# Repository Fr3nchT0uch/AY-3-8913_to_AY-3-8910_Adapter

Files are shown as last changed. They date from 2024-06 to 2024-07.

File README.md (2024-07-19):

# AY-3-8913 to AY-3-8910 Adapter

A simple adapter to replace the AY-3-8913 with the AY-3-8910 (or the YM2149)

## Why to replace the AY-3-8913 ?
If you've read this article https://www.fenarinarsa.com/?p=3183, you know that there's a chance your Mockingboard with AY-3-8913 will sound *weird* under certain circumstances.

Here a short video to hear the difference between a faulty AY-3-8913 and an AY-3-8910 in action (featuring Digidream 2): https://www.youtube.com/watch?v=_qslugOY2Dw

That's why we decided to do an adapter to easily replace the AY-3-8913 with the AY-3-8910 (or the YM2149) which does not suffer from the same issue and is more readily available.
We have made several designs giving you the choice for your use!
And they can of course be used as a basis for your own project! 

**Note about the Phasor Card**: these adapters are designed to be used primarily on a *Mockingboard*. For the *Phasor*, as there are 4 AY-3-8913s potentially to be replaced, it will probably be necessary to use a *daughter board* as adapter. This is beyond the scope of this project (for now...)

## Credits:  
Original idea: French Touch (grouik/fenarinarsa)  
http://fr3nch.t0uch.free.fr/  
Final design (and all the hard work!): Mr Jean-Fred  
https://github.com/Jean-Fred64

*French Touch would especially like to thank Mr Jean-Fred, without whom this project would never have been possible. It's thanks to him that an embryonic schematic was transformed into a viable project!*

## License:
GNU GENERAL PUBLIC LICENSE 3

## Reference:
Datasheets:  
AY-3-8910: https://map.grauw.nl/resources/sound/generalinstrument_ay-3-8910.pdf  
YM2149: http://www.ym2149.com/ym2149.pdf  

Mockingboard Info:  
https://en.wikipedia.org/wiki/Mockingboard
https://www.reactivemicro.com/product/mockingboard-assembled-or-kit/

Manufacturing PCB:  
https://www.kicad.org/  
https://jlcpcb.com/  
https://www.pcbway.com/

----  
## PCB designs:

## "Angle" version for Mockingboard (Two different PCBs for each AY-3-8913)
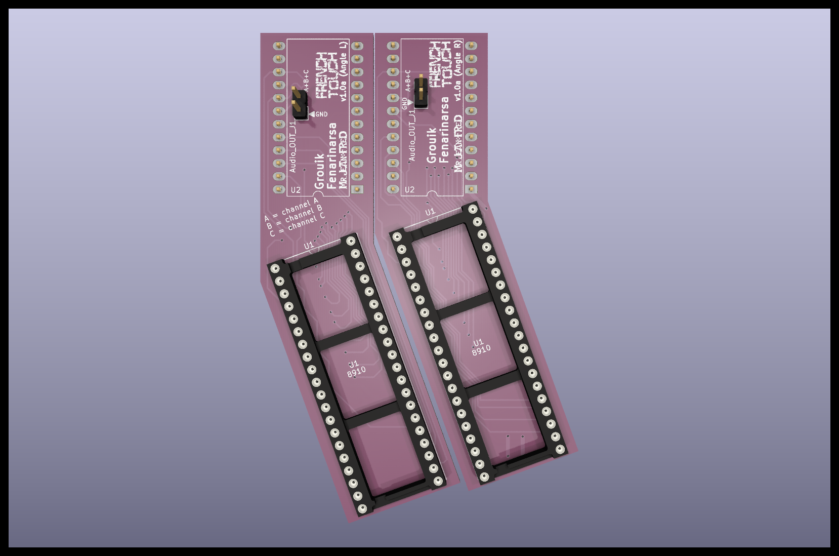
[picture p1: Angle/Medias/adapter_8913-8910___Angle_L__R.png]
adapter 8913-8910 Angle Left

 
**LEFT** for *top* AY-3-8913:
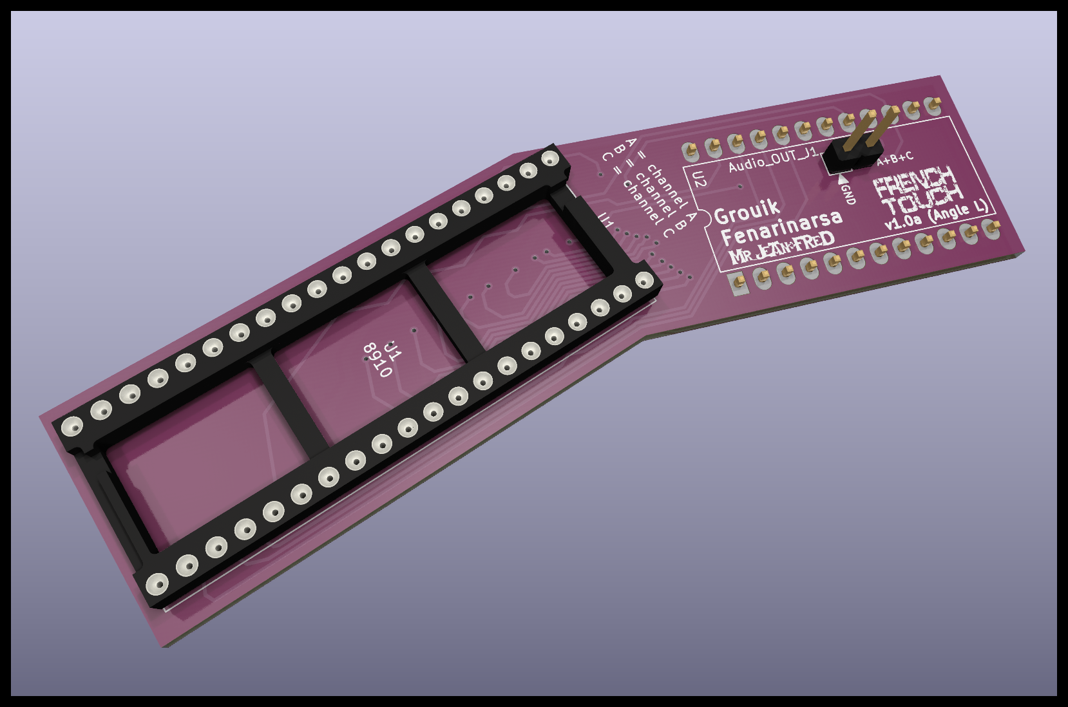
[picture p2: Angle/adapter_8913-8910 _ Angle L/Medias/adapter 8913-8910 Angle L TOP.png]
adapter 8913-8910 Angle Left


**RIGHT** for *bottom* AY-3-8913:
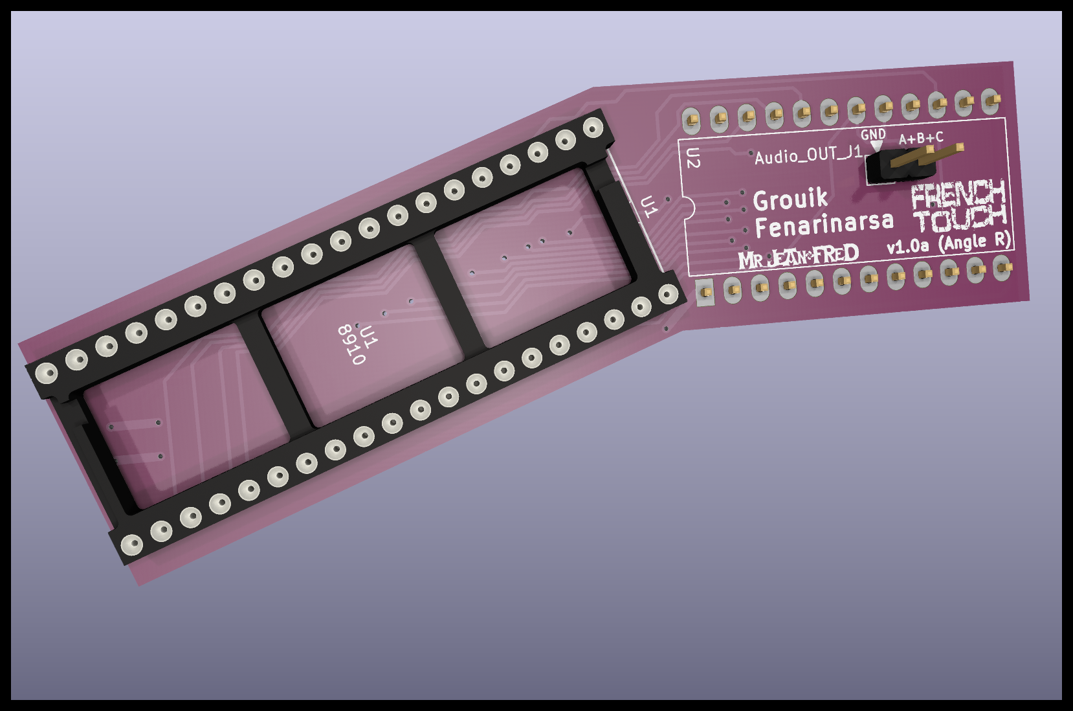
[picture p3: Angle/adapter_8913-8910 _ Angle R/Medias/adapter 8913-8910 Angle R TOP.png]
adapter 8913-8910 Angle Left


- to replace one or **two** AY-3-8913 on your Mockingboard.
- you must use each version for the TOP and BOTTOM AY-3-8913 on your Mockbingboard.
- note: pay attention to the insertion direction of the AY-3-8910 on the adapter.

----  

## "Triangle" version for Mockingboard (A single PCB for the two AY-3-8913s)
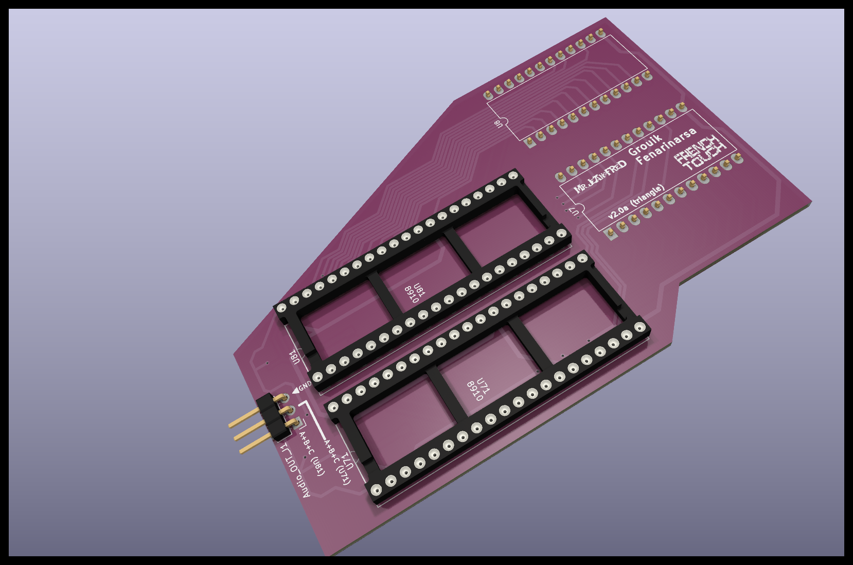
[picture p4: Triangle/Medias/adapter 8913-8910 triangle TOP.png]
adapter 8913-8910 zoom header


- alternative (and ultimate) version to replace the TWO AY-3-8913 on the Mockingboard on the same board.

----
## "Normal" general version
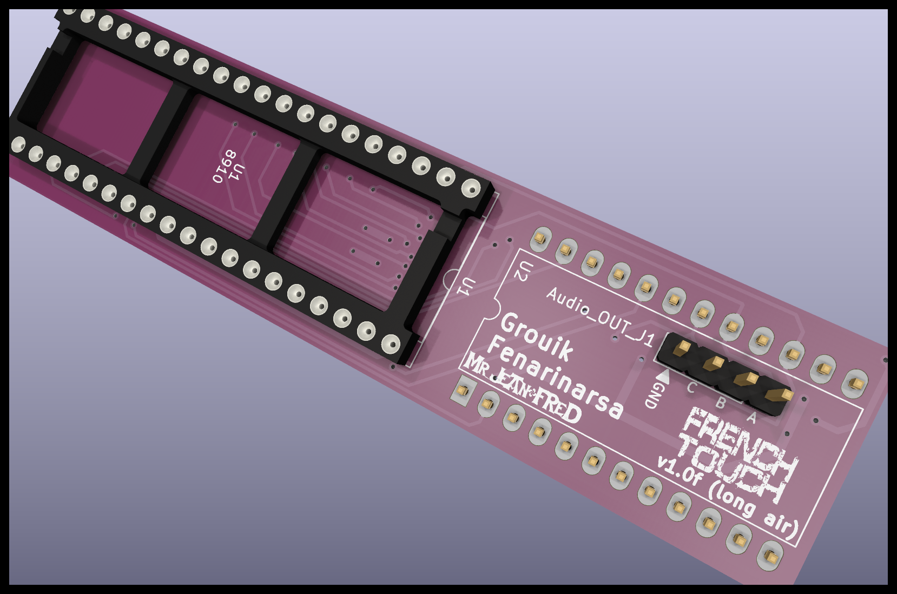
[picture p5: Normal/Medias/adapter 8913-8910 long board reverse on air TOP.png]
adapter 8913-8910 Normal


- to replace only **one** AY-3-8913 on the Mockingboard (the **bottom** one only!).
- to replace the AY-3-8913 on other machines (for example: some old Pinball *soundcards*).
- note: pay attention to the insertion direction of the AY-3-8910 on the adapter.

- **WARNING**: do not use this model if you want to replace the **TWO** AY-3-8913s on your Mockingboard because you will not be able to close the Apple II cover! Use the other designs instead!

## Audio Output:

Each PCD design has an **Audio Output** (pins) for direct connection to the AY-3-8910/YM2149 without using the Mockingboard amplification part. This allows for much better quality with a line level output.

To be heard here: https://www.youtube.com/watch?v=SWxKD_74ifs

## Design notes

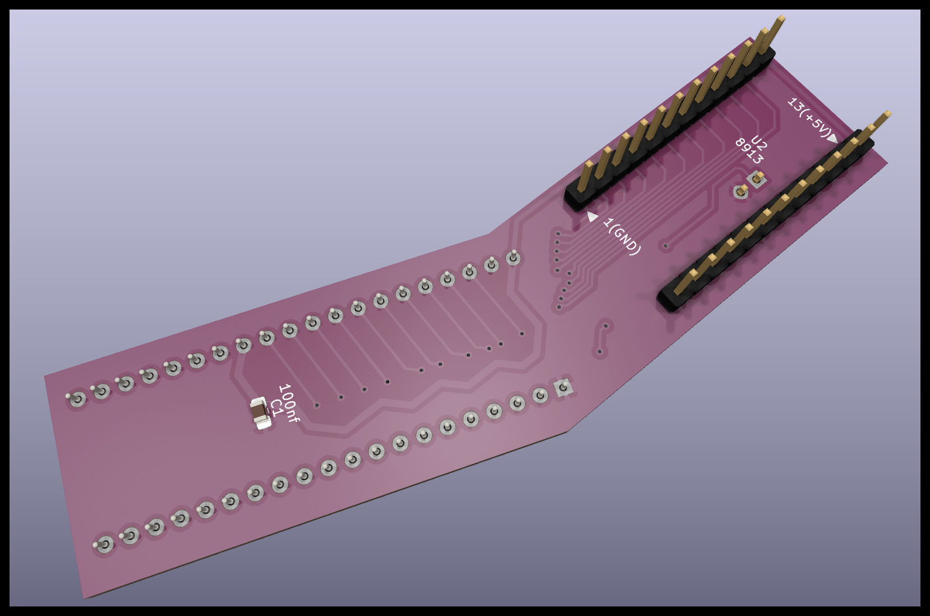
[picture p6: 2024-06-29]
Angle/adapter_8913-8910 _ Angle L/Medias/adapter 8913-8910 Angle L BACK.png

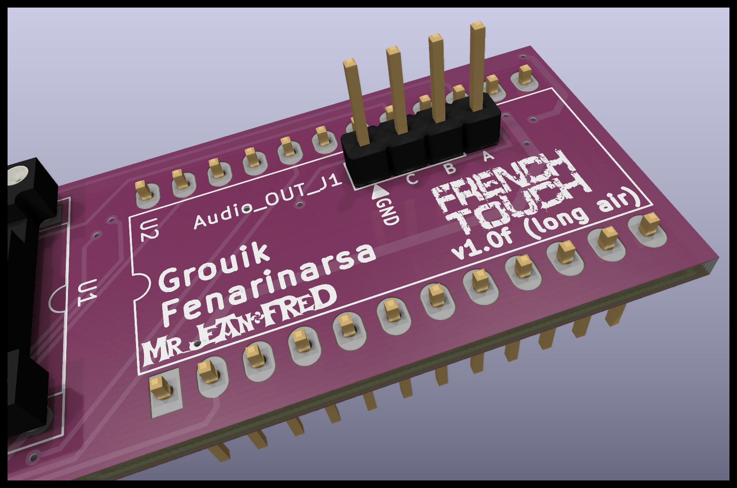
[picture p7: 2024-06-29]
Normal/Medias/adapter 8913-8910 zoom header pin 2.54 mm.png

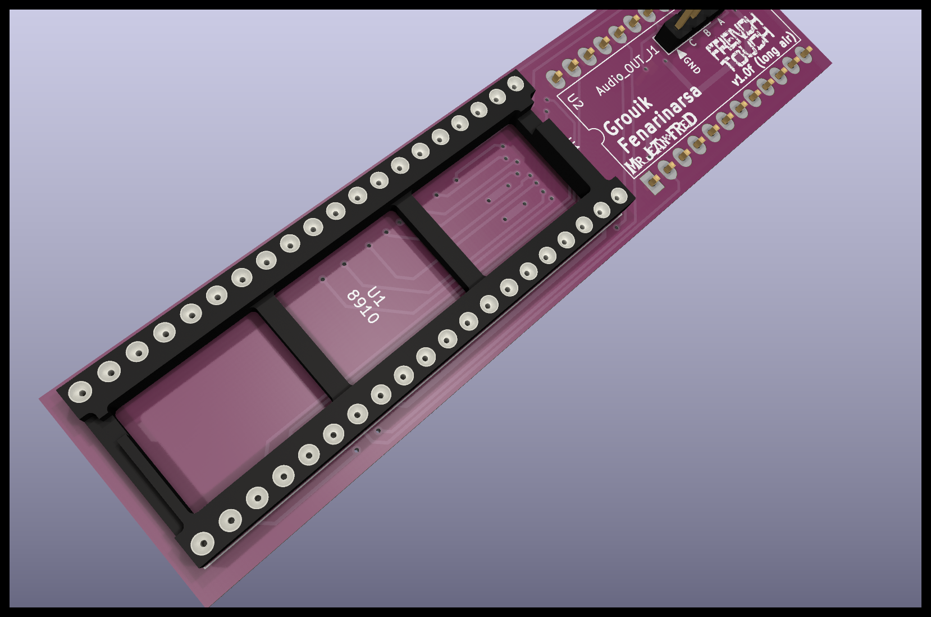
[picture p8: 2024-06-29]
Normal/Medias/adapter 8913-8910 8910.png

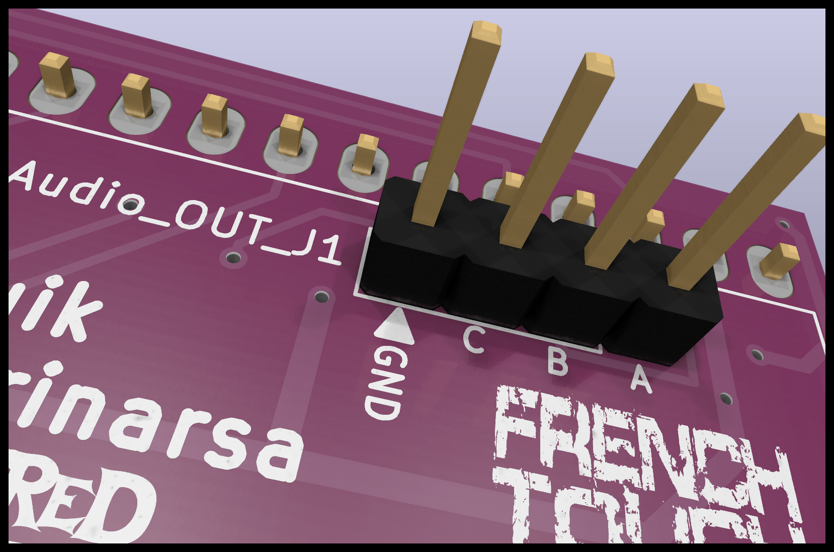
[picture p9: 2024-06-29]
Normal/Medias/adapter 8913-8910 zoom header pin.png

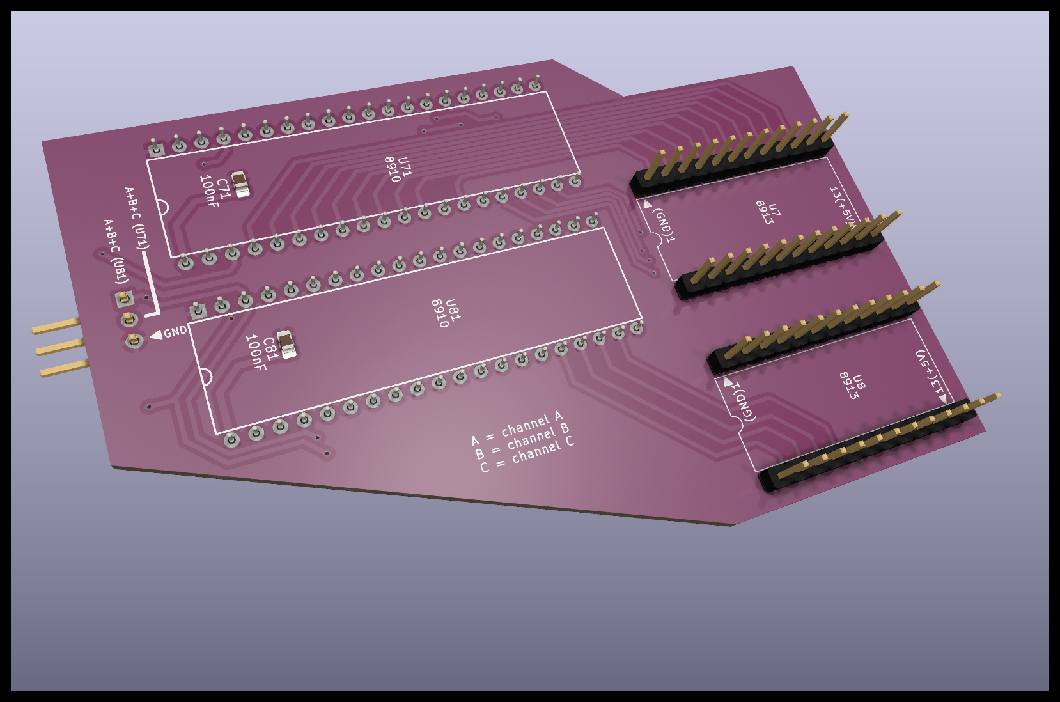
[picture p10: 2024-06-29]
Triangle/Medias/adapter 8913-8910 triangle BACK.png

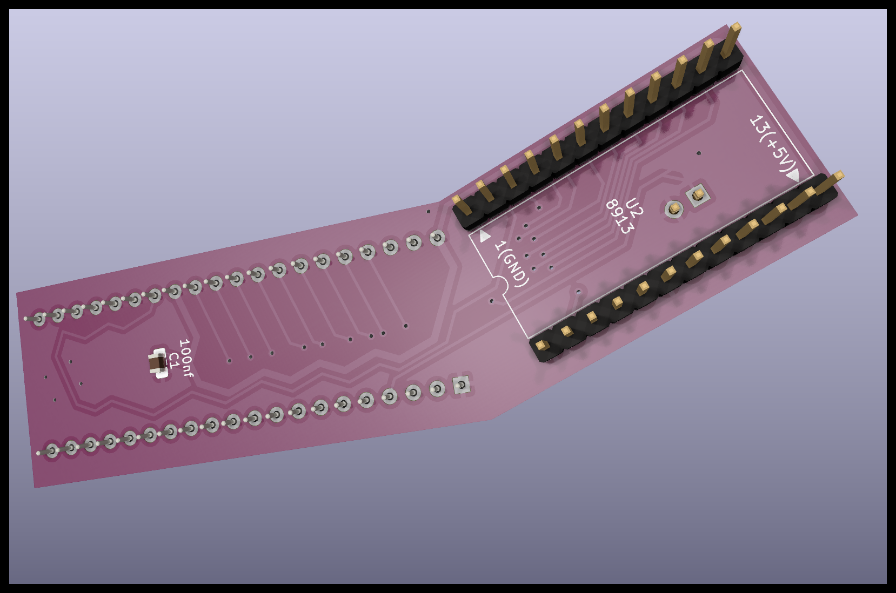
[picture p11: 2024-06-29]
Angle/adapter_8913-8910 _ Angle R/Medias/adapter 8913-8910 Angle R BACK.png

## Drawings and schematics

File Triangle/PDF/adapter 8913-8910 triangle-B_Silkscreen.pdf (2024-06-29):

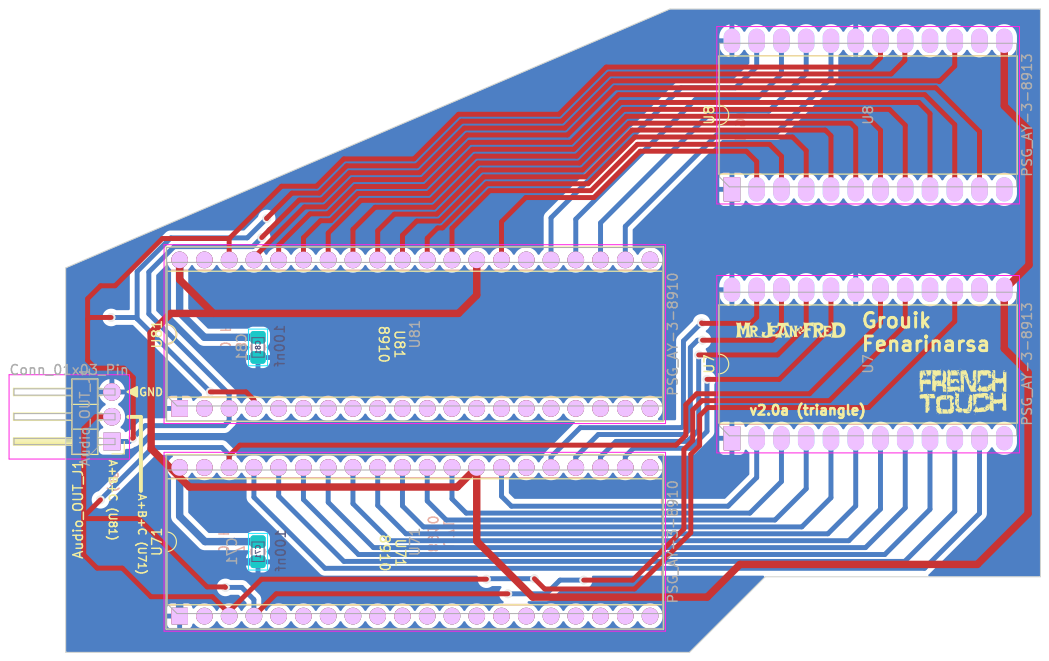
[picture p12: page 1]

C71 100nF C81 100nF A+B+C (U71) A+B+C (U81) A = channel A B = channel B C = channel C U8 8913 (GND)1 (GND)1 U7 8913 13(+5V) U81 8910 GND U71 8910 13(+5V) 100nf C71 100nf C81 A+B+C (U81)U71 8910 GND Grouik Fenarinarsa U81 8910

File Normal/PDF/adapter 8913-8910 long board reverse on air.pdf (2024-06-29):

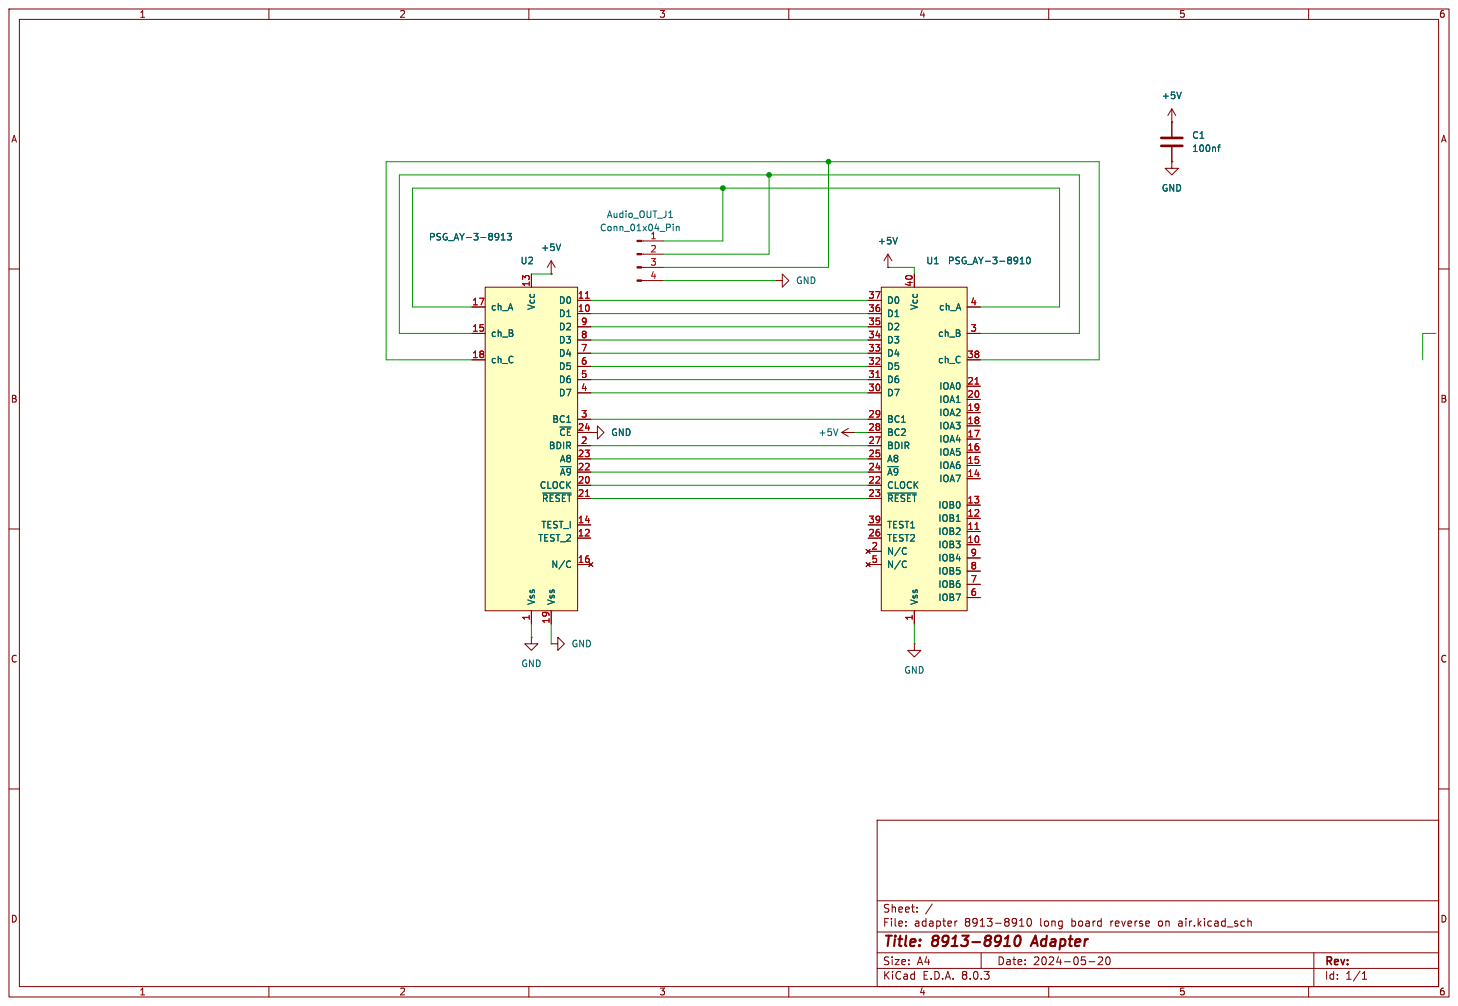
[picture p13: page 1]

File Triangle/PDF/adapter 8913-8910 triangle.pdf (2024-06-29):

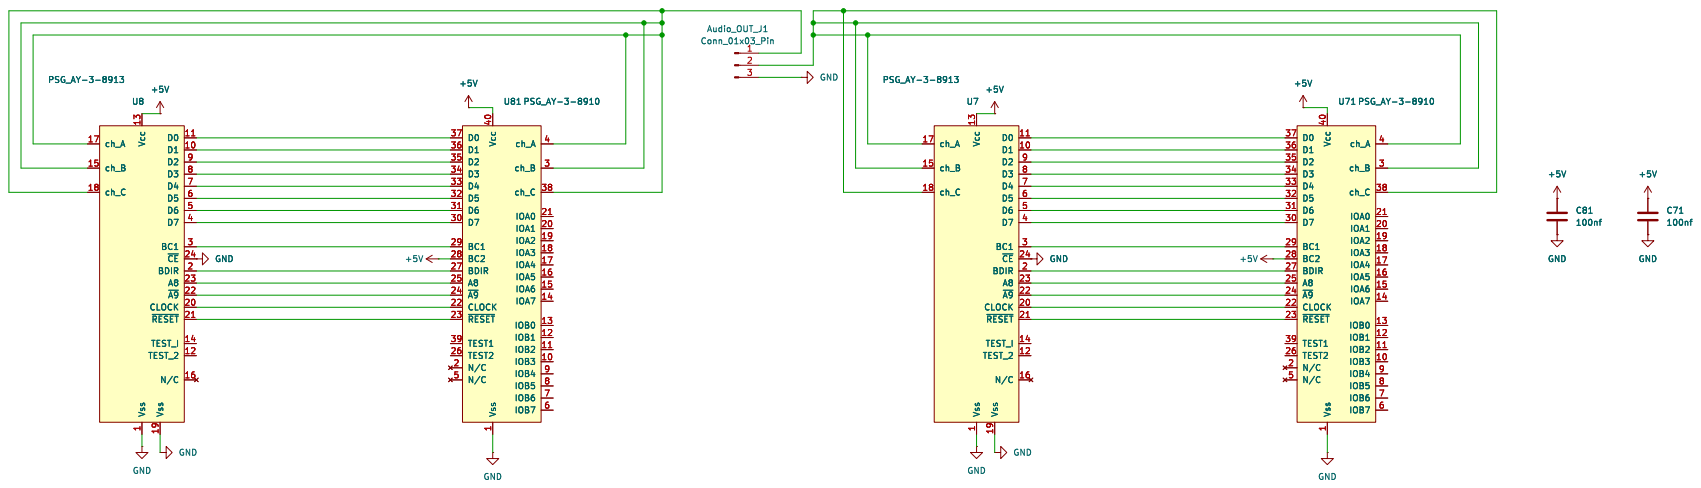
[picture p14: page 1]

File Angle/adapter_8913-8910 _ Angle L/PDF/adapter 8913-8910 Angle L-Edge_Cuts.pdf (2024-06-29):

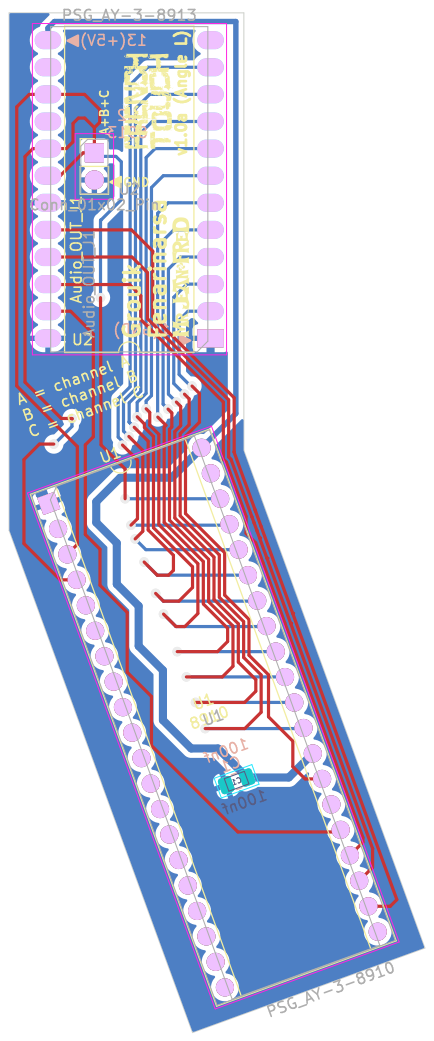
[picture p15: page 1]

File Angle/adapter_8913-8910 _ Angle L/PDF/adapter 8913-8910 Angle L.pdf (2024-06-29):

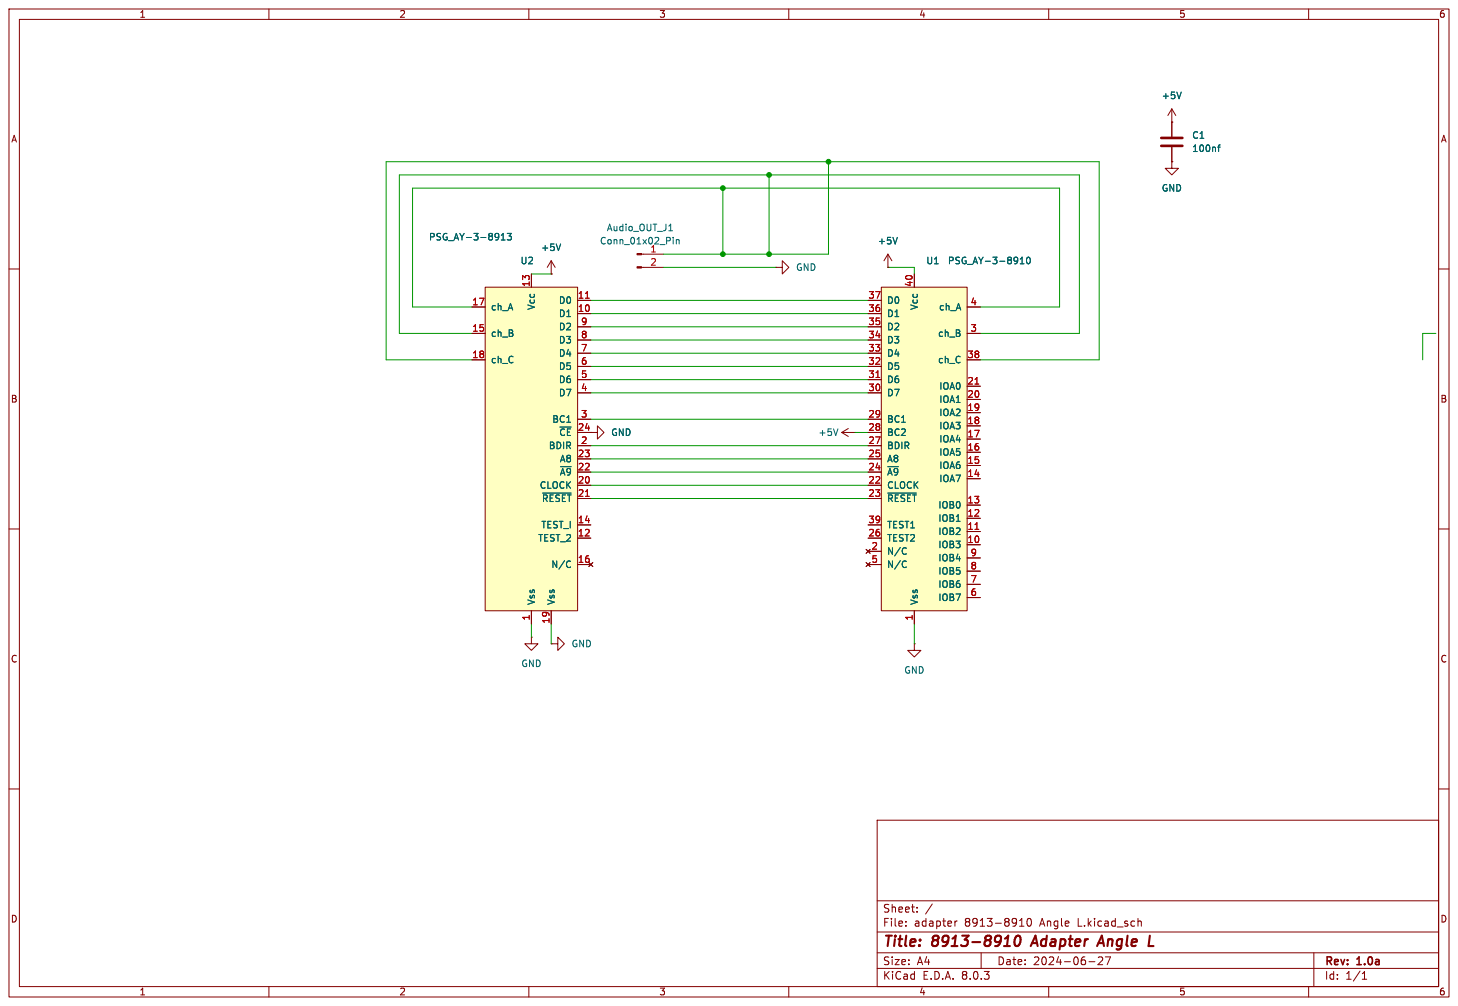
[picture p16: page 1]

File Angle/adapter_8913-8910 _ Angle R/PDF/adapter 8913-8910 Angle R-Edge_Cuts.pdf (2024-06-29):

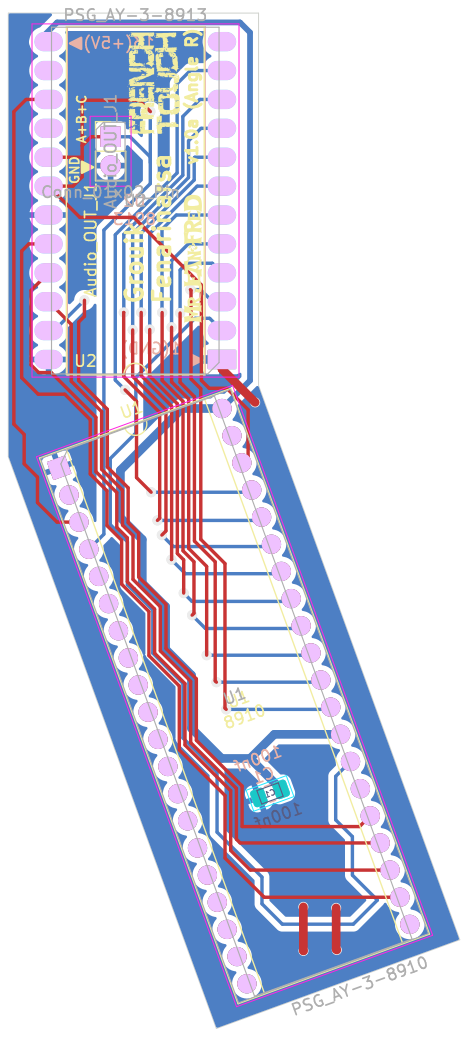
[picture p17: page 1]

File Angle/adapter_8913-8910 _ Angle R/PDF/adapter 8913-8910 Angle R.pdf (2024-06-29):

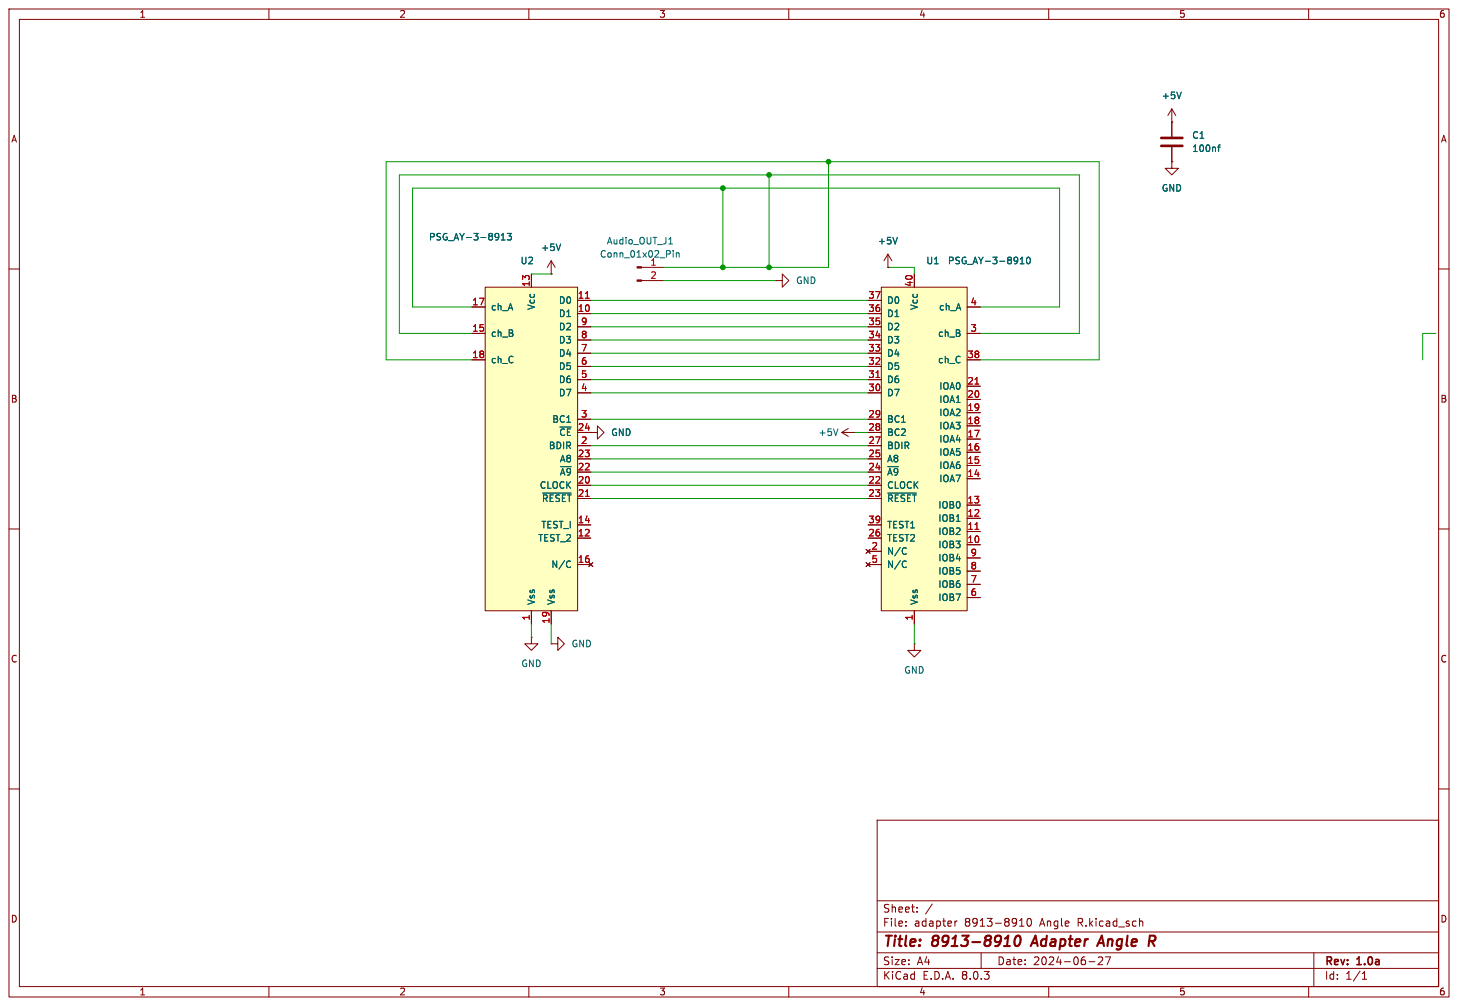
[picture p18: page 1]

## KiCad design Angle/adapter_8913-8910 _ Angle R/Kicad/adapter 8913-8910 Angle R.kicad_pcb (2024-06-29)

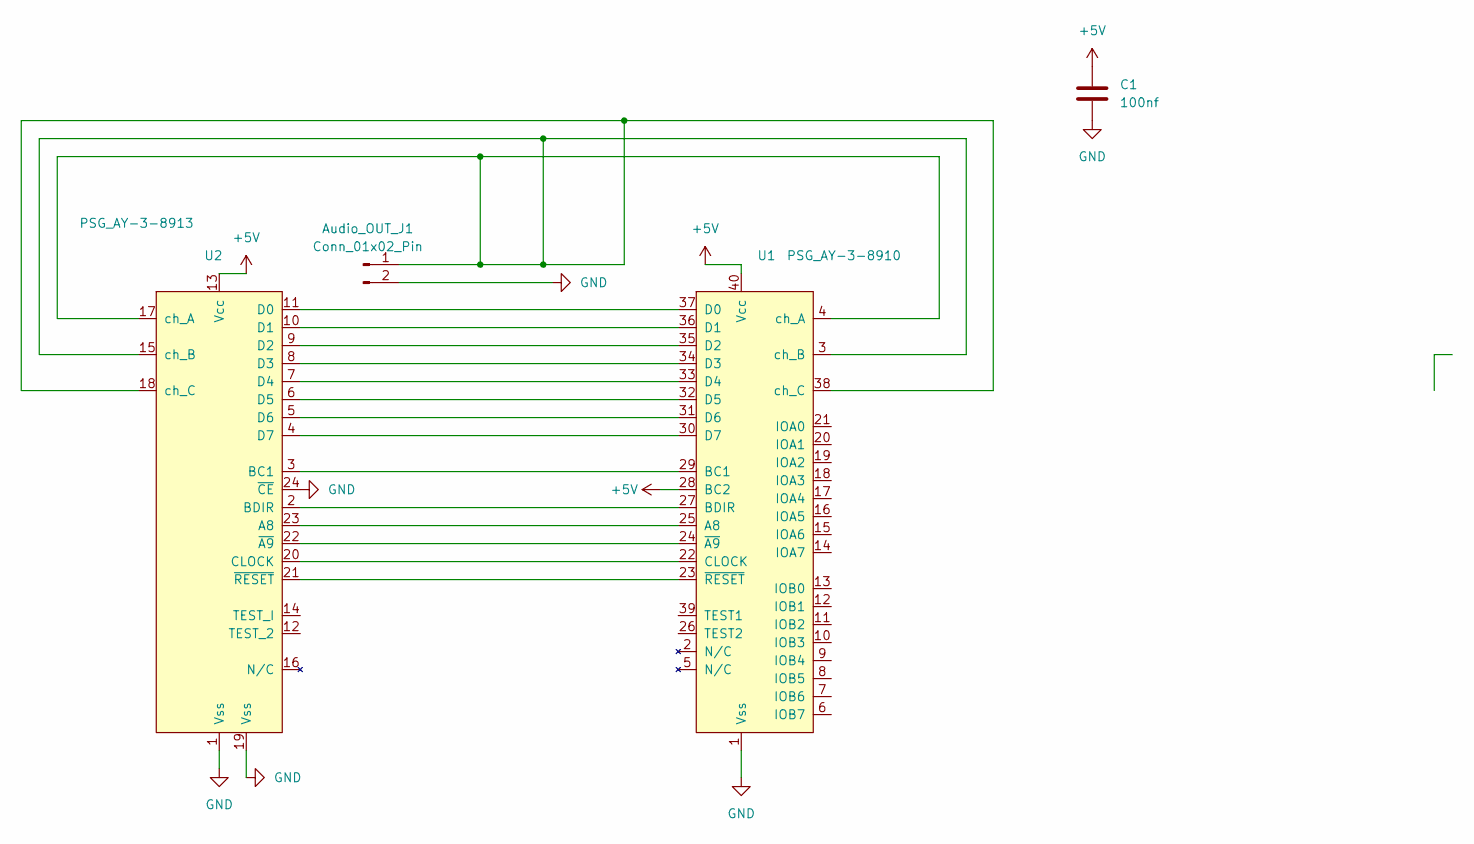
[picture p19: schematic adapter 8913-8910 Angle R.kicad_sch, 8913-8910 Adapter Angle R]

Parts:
Audio_OUT_J1: Conn_01x02_Pin; PinHeader_1x02_P2.54mm_Vertical
C1: 100nf; C_0805_2012Metric_Pad1.18x1.45mm_HandSolder
U1: PSG_AY-3-8910; DIP-40_W15.24mm_Socket
U2: PSG_AY-3-8913; DIP-24_W15.24mm_LongPads

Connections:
+5V: C1.1, U1.28 (BC2), U1.40 (Vcc), U2.13 (Vcc)
GND: Audio_OUT_J1.2, C1.2, U1.1 (Vss), U2.1 (Vss), U2.19 (Vss), U2.24 (~CE)
unnamed: Audio_OUT_J1.1, U1.3 (ch_B), U1.4 (ch_A), U1.38 (ch_C), U2.15 (ch_B), U2.17 (ch_A), U2.18 (ch_C)
unnamed: U1.25 (A8), U2.23 (A8)
unnamed: U1.29 (BC1), U2.3 (BC1)
unnamed: U1.27 (BDIR), U2.2 (BDIR)
unnamed: U1.22 (CLOCK), U2.20 (CLOCK)
unnamed: U1.37 (D0), U2.11 (D0)
unnamed: U1.36 (D1), U2.10 (D1)
unnamed: U1.35 (D2), U2.9 (D2)
unnamed: U1.34 (D3), U2.8 (D3)
unnamed: U1.33 (D4), U2.7 (D4)
unnamed: U1.32 (D5), U2.6 (D5)
unnamed: U1.31 (D6), U2.5 (D6)
unnamed: U1.30 (D7), U2.4 (D7)
unnamed: U1.24 (~A9), U2.22 (~A9)
unnamed: U1.23 (~RESET), U2.21 (~RESET)

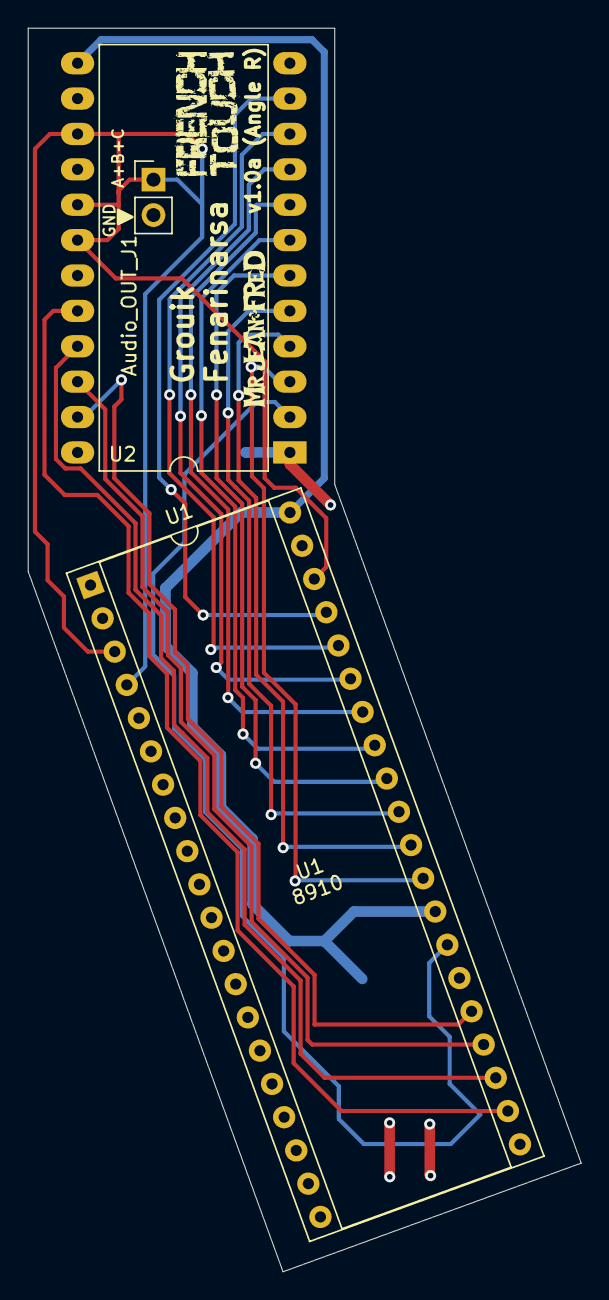
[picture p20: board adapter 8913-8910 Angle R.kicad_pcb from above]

Board: 2 copper layers, 39.7 x 89.3 mm, 4 parts (1 on the bottom side), 17 nets.

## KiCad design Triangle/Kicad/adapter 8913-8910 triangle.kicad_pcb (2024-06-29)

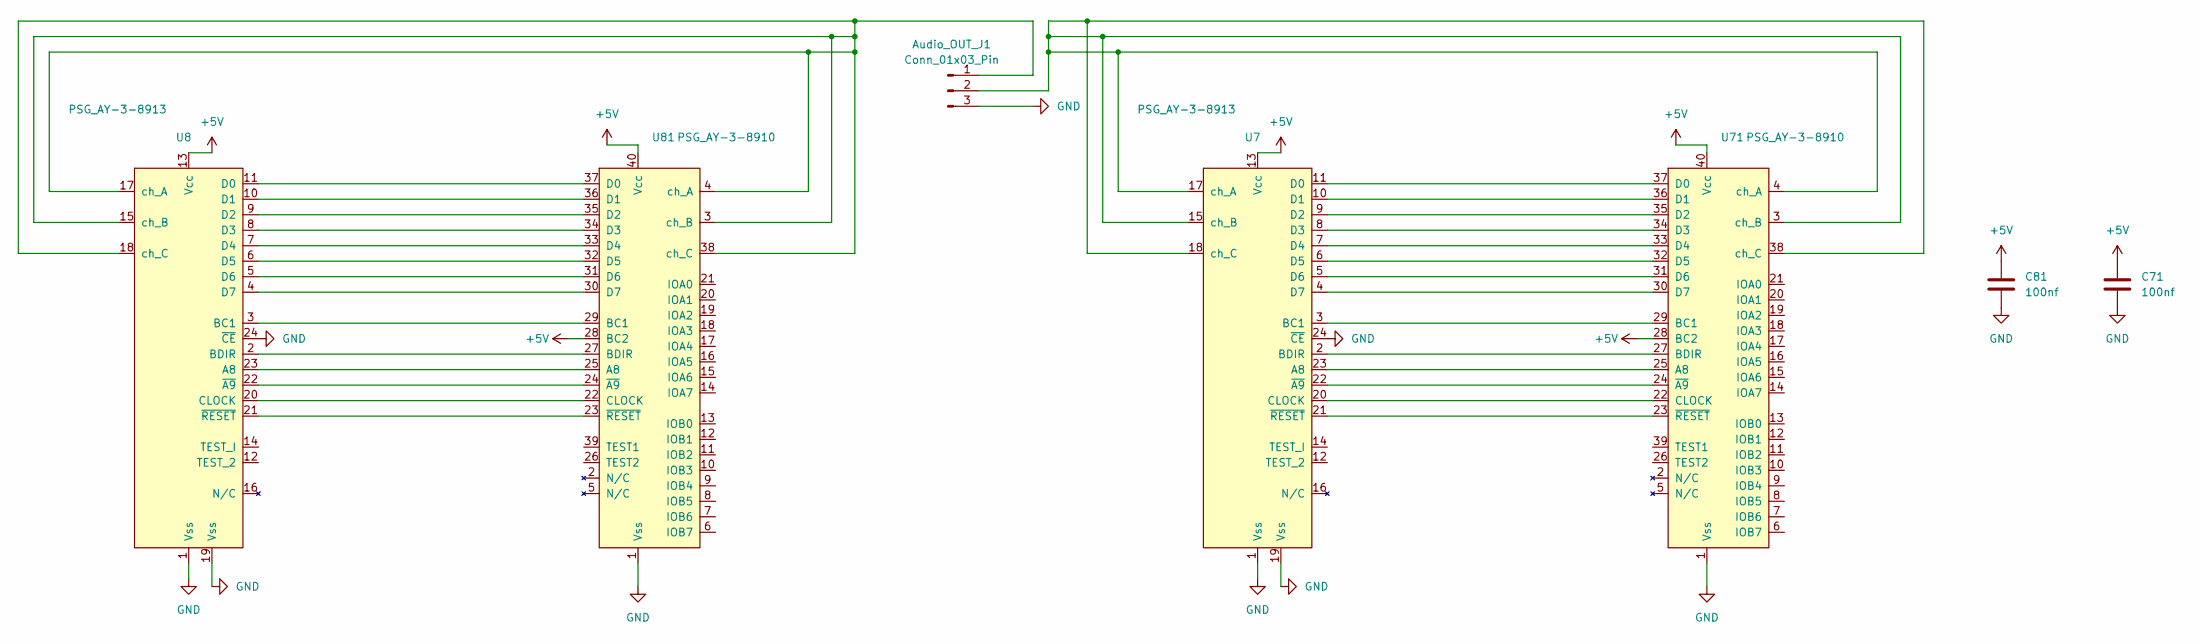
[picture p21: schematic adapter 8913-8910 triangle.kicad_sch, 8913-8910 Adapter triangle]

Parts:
Audio_OUT_J1: Conn_01x03_Pin; PinHeader_1x03_P2.54mm_Horizontal
C71, C81: 100nf; C_0805_2012Metric_Pad1.18x1.45mm_HandSolder
U7, U8: PSG_AY-3-8913; DIP-24_W15.24mm_LongPads
U71, U81: PSG_AY-3-8910; DIP-40_W15.24mm_Socket

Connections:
+5V: C71.1, C81.1, U7.13 (Vcc), U8.13 (Vcc), U71.28 (BC2), U71.40 (Vcc), U81.28 (BC2), U81.40 (Vcc)
GND: Audio_OUT_J1.3, C71.2, C81.2, U7.1 (Vss), U7.19 (Vss), U7.24 (~CE), U8.1 (Vss), U8.19 (Vss), U8.24 (~CE), U71.1 (Vss), U81.1 (Vss)
unnamed: Audio_OUT_J1.1, U8.15 (ch_B), U8.17 (ch_A), U8.18 (ch_C), U81.3 (ch_B), U81.4 (ch_A), U81.38 (ch_C)
unnamed: Audio_OUT_J1.2, U7.15 (ch_B), U7.17 (ch_A), U7.18 (ch_C), U71.3 (ch_B), U71.4 (ch_A), U71.38 (ch_C)
unnamed: U7.23 (A8), U71.25 (A8)
unnamed: U7.3 (BC1), U71.29 (BC1)
unnamed: U7.2 (BDIR), U71.27 (BDIR)
unnamed: U7.20 (CLOCK), U71.22 (CLOCK)
unnamed: U7.11 (D0), U71.37 (D0)
unnamed: U7.10 (D1), U71.36 (D1)
unnamed: U7.9 (D2), U71.35 (D2)
unnamed: U7.8 (D3), U71.34 (D3)
unnamed: U7.7 (D4), U71.33 (D4)
unnamed: U7.6 (D5), U71.32 (D5)
unnamed: U7.5 (D6), U71.31 (D6)
unnamed: U7.4 (D7), U71.30 (D7)
unnamed: U7.22 (~A9), U71.24 (~A9)
unnamed: U7.21 (~RESET), U71.23 (~RESET)
unnamed: U8.23 (A8), U81.25 (A8)
unnamed: U8.3 (BC1), U81.29 (BC1)
unnamed: U8.2 (BDIR), U81.27 (BDIR)
unnamed: U8.20 (CLOCK), U81.22 (CLOCK)
unnamed: U8.11 (D0), U81.37 (D0)
unnamed: U8.10 (D1), U81.36 (D1)
unnamed: U8.9 (D2), U81.35 (D2)
unnamed: U8.8 (D3), U81.34 (D3)
unnamed: U8.7 (D4), U81.33 (D4)
unnamed: U8.6 (D5), U81.32 (D5)
unnamed: U8.5 (D6), U81.31 (D6)
unnamed: U8.4 (D7), U81.30 (D7)
unnamed: U8.22 (~A9), U81.24 (~A9)
unnamed: U8.21 (~RESET), U81.23 (~RESET)

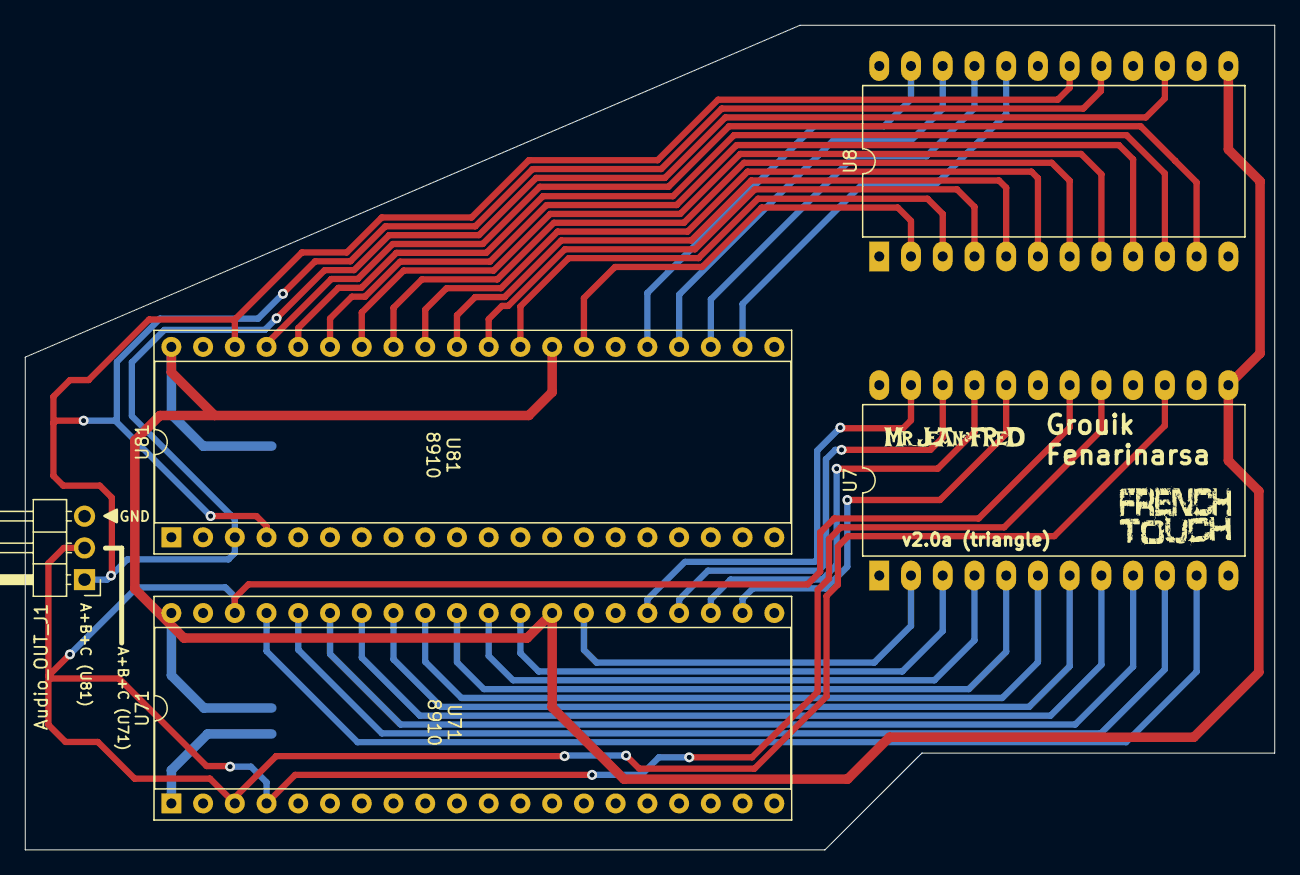
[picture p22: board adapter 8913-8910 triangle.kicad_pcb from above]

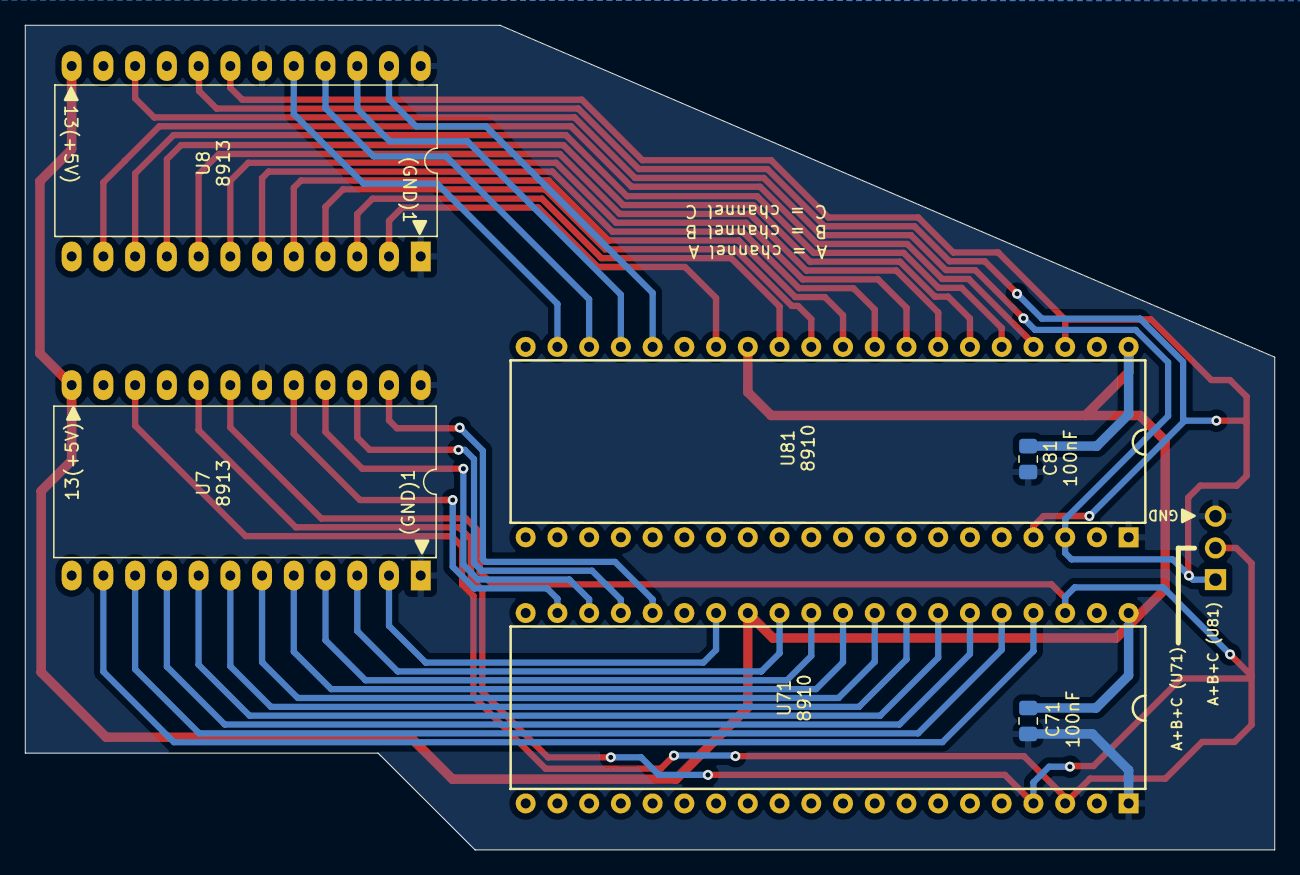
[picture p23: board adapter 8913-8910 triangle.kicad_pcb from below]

Board: 2 copper layers, 100.0 x 66.0 mm, 7 parts (2 on the bottom side), 32 nets.
